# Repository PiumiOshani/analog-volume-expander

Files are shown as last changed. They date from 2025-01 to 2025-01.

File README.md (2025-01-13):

# Analog Volume Expander

**Real-time audio volume expander to enhance the dynamic range of audio signals.**

## 📖 Project Overview
This project involves the design and implementation of an **Analog Volume Expander**, which enhances the dynamic range of audio signals by applying upward expansion. It is tailored for applications like recording, broadcasting, and live sound systems.

### Key Features
- Real-time signal processing with minimal latency.
- User-configurable threshold and expansion ratio.
- Efficient **Control Voltage Processor** and **Voltage-Controlled Amplifier (VCA)**.
- Integrated notch filter to eliminate power line interference.
- Dual-layer PCB design and custom 3D-printed enclosure.

---

## 🛠 System Design
### Functional Block Diagram

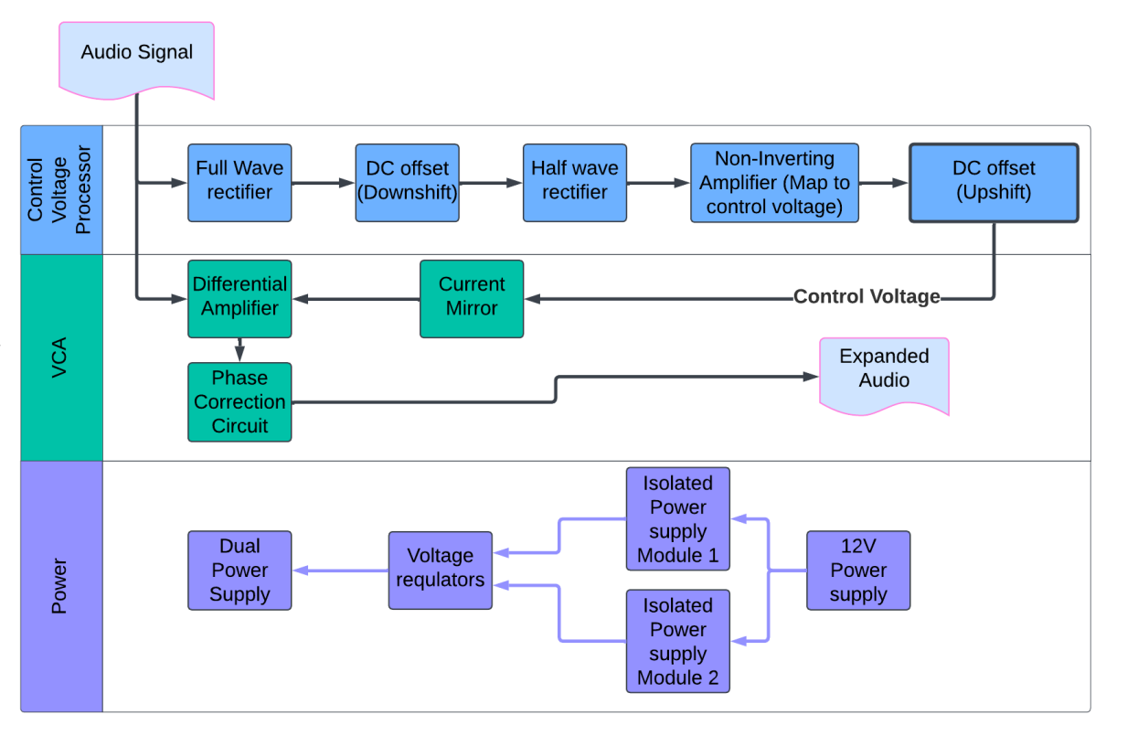
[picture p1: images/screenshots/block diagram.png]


### Core Components
- **Control Voltage Processor**: Processes the input signal to generate control voltages.
- **Voltage-Controlled Amplifier (VCA)**: Adjusts the gain dynamically.
- **Notch Filter**: Removes power line noise (50Hz).
- **Power Supply**: Provides stable and isolated power to the system.

---

## 📸 Project Highlights
### PCB Design
- **2-layer PCB Design**: Designed using Altium Designer, manufactured via JLCPCB.
- **Key Features**:
  - Efficient layout with minimal wiring.
  - Proper power-signal separation for reliability.

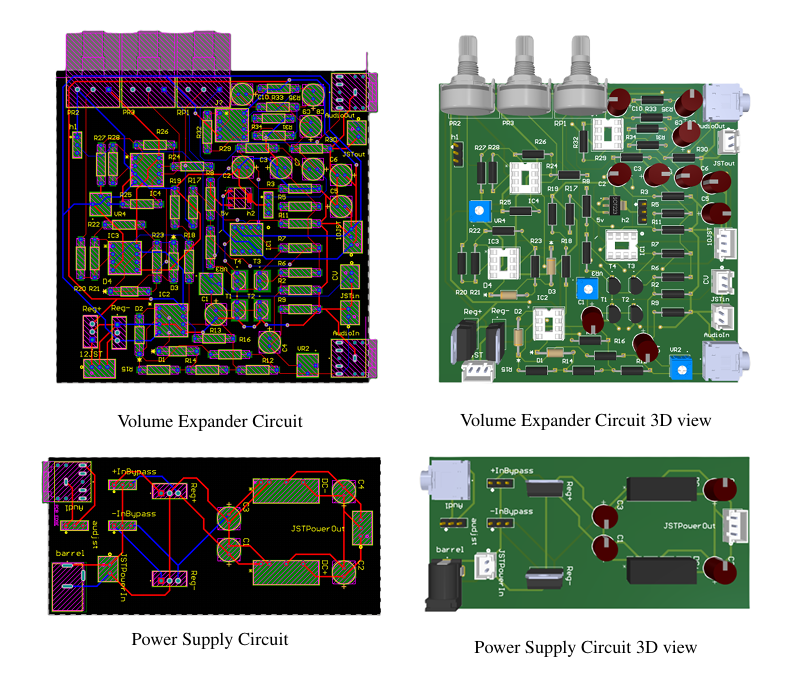
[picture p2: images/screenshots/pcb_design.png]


### Enclosure Design
- **3D-printed enclosure**:
  - Designed in SolidWorks.
  - Printed using durable PLA+ material.
- **Dimensions**: 154 mm × 116 mm × 70 mm.

<div style="display: flex; justify-content: space-between;">
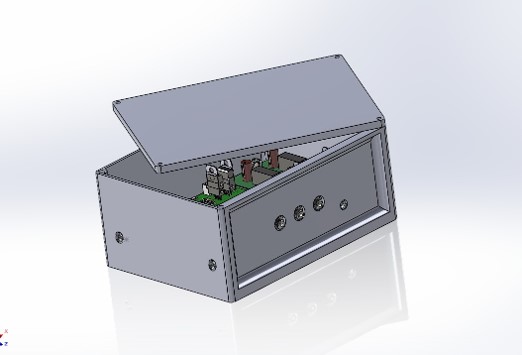
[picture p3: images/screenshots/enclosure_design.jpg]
    
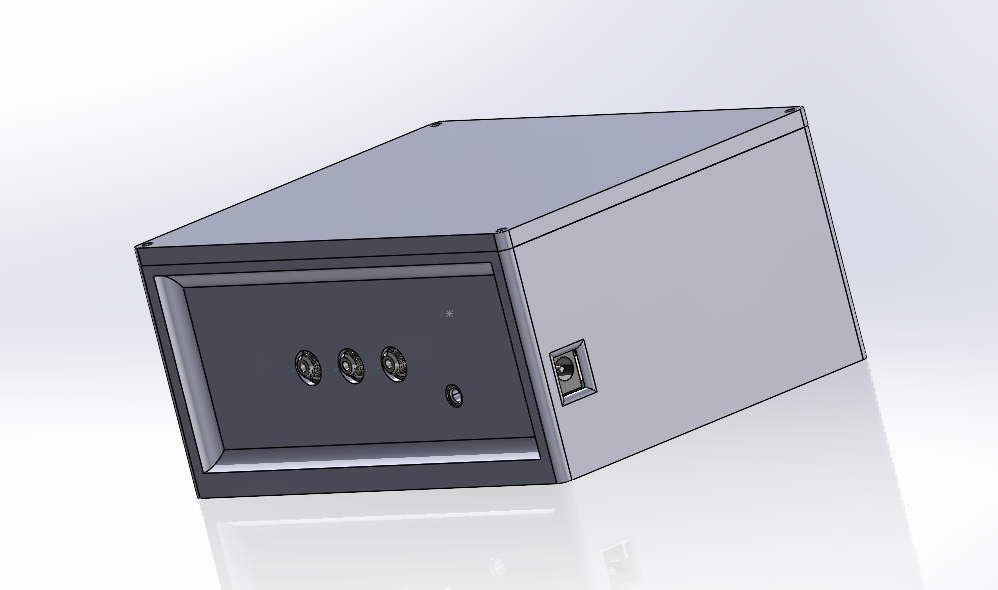
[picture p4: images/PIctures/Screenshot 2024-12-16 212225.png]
    
</div>

### Final Product

<div style="display: flex; justify-content: space-between;">
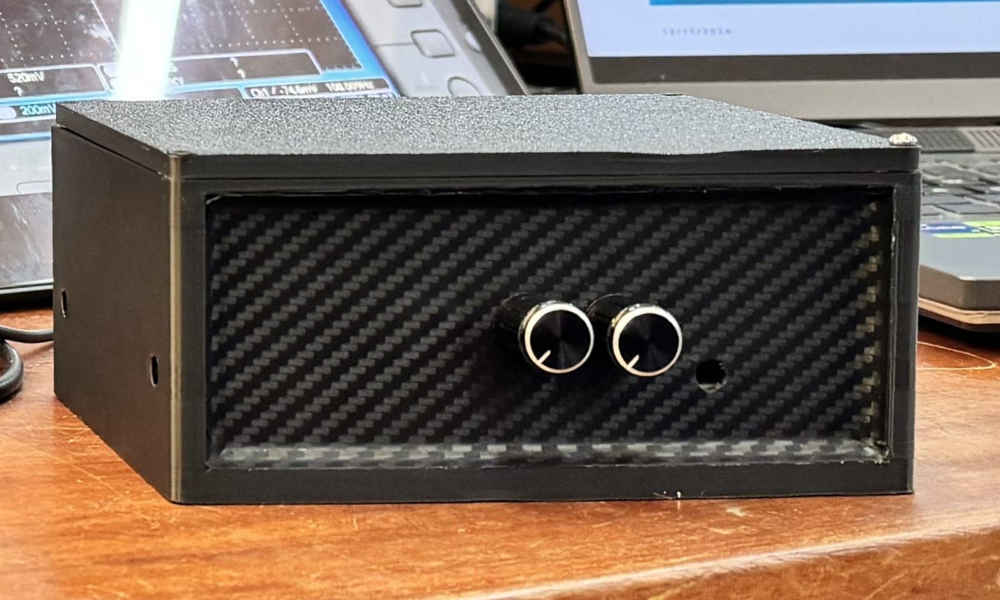
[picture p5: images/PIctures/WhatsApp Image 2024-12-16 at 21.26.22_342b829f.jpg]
    
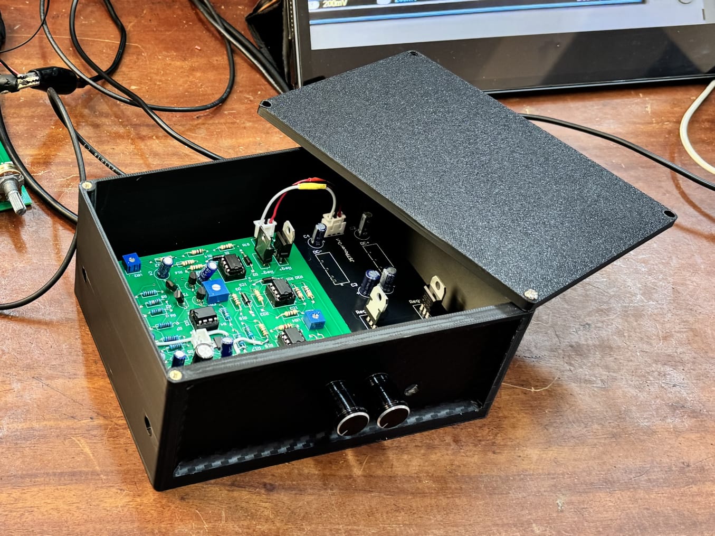
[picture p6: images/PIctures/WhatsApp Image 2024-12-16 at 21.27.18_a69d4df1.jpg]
    
</div>

 ## 👥 Group Members
 | Name | Index Number |Email|
|------|--------------|--------------|
 | Balasooriya B A P I | 220054N | balasooriyabapi.22@uom.lk
 | Dewasumithra M P O | 220112R |piumioshani@gmail.com|
 | Dineshara M C | 220128V |chandupadineshara@gmail.com|
 | Diunugala C H | 220143L |chamathdiunugala@gmail.com|

---




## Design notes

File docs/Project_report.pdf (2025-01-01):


Department of Electronic & Telecommunication Engineering, University of Moratuwa, Sri Lanka.

## Volume Expander

Group Members:

220054N | Balasooriya B.A.P.I.
220112R | Dewasumithra M.P.O.
220128V | Dineshara M.C.
220143L | Diunugala C.H.

Submitted in partial fulfillment of the requirements for the module EN 2091 Laboratory Practice and Projects

18/12/2024

Volume Expander | Group No : 5

Abstract
This report provides an overview of the design and implementation of a real-time audio volume expander to enhance dynamic range of audio signals. The system employs a control voltage processor and voltage-controlled amplifier (VCA) architecture to perform upward expansion of signals exceeding a user-defined threshold. Key components of the system includes a custom signal processor, a customized VCA circuit achieving 3-4 dB gain, and a notch filter to eliminate power line interference. The implementation features a dual-layer PCB design, custom 3D-printed enclosure, and isolated power supply for powering ciruits. Hardware testing and LTspice simulations validated the system’s functionality, demonstrating successful dynamic range enhancement for audio applications in Audio systems.

i

### Contents

1 Introduction and Functionality | 1
2 System Architecture | 1
3 Component Selection | 4
4 PCB Design | 5
5 Enclosure Design | 6
6 Final Product | 6
7 Software Simulation and Hardware Testing | 7
8 Conclusion & Future Works | 9
9 Contribution of Group Members | 9

ii

### 1 Introduction and Functionality

Dynamic range is a fundamental characteristic of an audio signals, it is the ratio between the loudest and quietest possible sounds in the audio signal. Maintaining a proper dynamic range of an audio signal is essential to achieve clarity, naturalness, and overall quality in audio reproduction. Due to recording limitations, signal processing, and noise, interference audio signals suffer from dynamic range compression leading to a loss of audio detail and reduced audio fidelity. [1]
A volume expander (commonly known as Audio dynamic range expander) is used to increase the dynamic range of an audio signal, by improving the difference between the quietest and loudest parts of the audio waveform. [2] This process restores the natural dynamics of an audio signal, reducing unwanted background noise and enhancing audio clarity. This report details the design and implementation of a custom audio dynamic range expander capable of real-time signal processing for applications in recording, broadcasting, and live sound systems. [3]

Volume Expander Functions by analyzing the In-

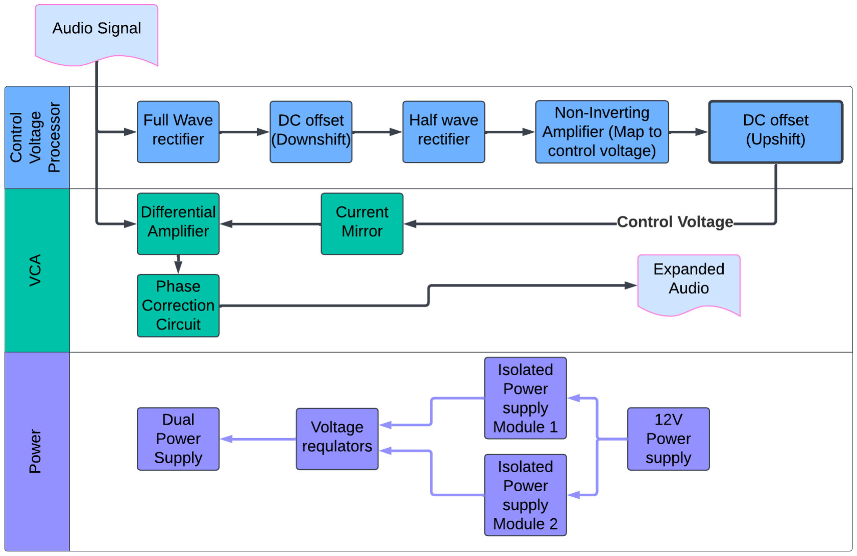
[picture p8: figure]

put audio signal and applying gain adjustments based on its amplitudes relative to a given threshold. Our implementation supports upward expansion of the audio signals which amplifies the levels of signals that exceeds the given threshold. The core functionality of the system is implemented through a control voltage processor which outputs a control voltage to a Voltage controlled amplifier (VCA), where gain applied to the audio signal is determined dynamically based on the amplitude of input signal. The user can configure the threshold and expansion ratio to customize the expander’s behavior. The system is designed to operate in real-time, ensuring minimal latency and seamless audio processing. It provides improved clarity and dynamic contrast, making it suitable for various audio applications, including music production, speech enhancement, and noise reduction.
Expander Parameters
- Threshold
The input level at which the expander activates. It triggers upward expansion for signals crossing above the threshold.
- Gain
The degree of amplification applied.

### 2 System Architecture

### 2.1 Functional Block Diagram

Figure 1: Functional Block Diagram

### 2.2 Control Voltage Processor

The Control Voltage Signal Processor is responsible for generating a control signal to dynamically adjust the gain of the audio signal using VCA. This processor includes several subsystems.

### 2.2.1 Full Wave Precision Rectifier

Converts the input audio signal to its absolute value, ensuring accurate amplitude detection. This component uses precision diodes and operational amplifiers to rectify both the positive and negative portions of the input signal without distortion.

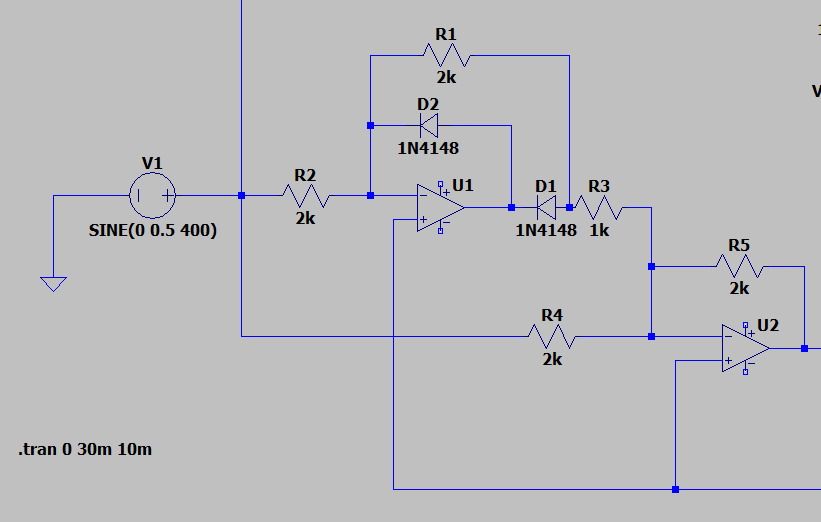
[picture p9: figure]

Figure 2: Full Wave Precision Rectifier Circuit

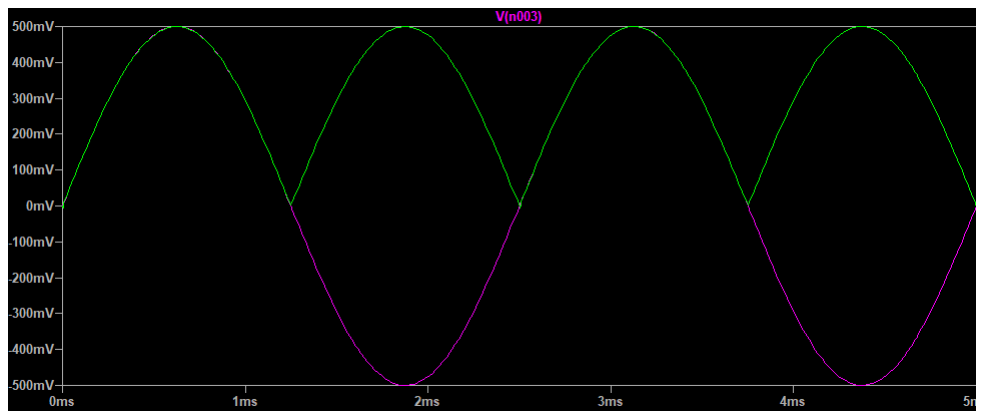
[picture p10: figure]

Figure 3: Full Wave Precision Rectifier Output

- Why Precision Rectifier? Standard diode rectifiers are unsuitable for low-amplitude signals due to forward voltage drops. Precision rectifiers eliminate this limitation, allowing accurate rectification of even millivolt-level signals.

### 2.2.2 DC offset(Downshift)

Adds a negative DC bias to the rectified signal to ensure that it operates within the appropriate voltage range for subsequent stages. Ideally adjusted to the unity gain voltage of the voltage controlled amplifier. This reference voltage depends on the threshold value that the user can control.

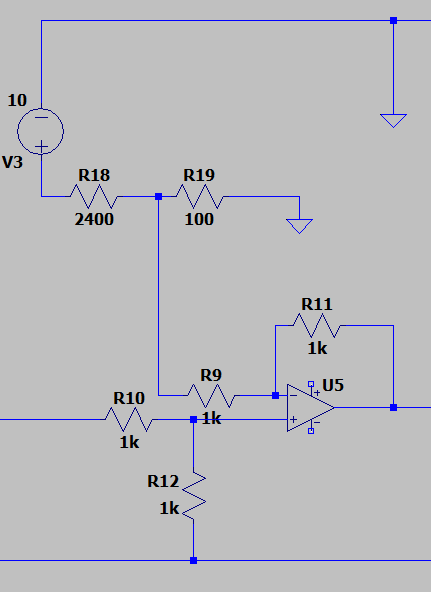
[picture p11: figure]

Figure 4: DC Downshift Circuit

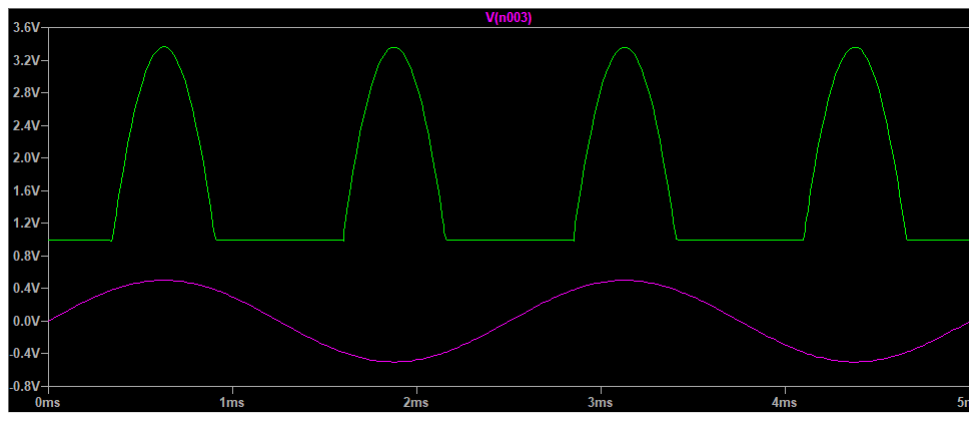
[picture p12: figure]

Figure 5: DC Downshift Output

### 2.2.3 Half Wave Precision Rectifier

Cutoff the signal that lies below the threshold level and extract accurate envelope of the audio signal. The resulting waveform represents the instantaneous amplitude of the signal above the threshold. A half wave precision rectifier is used to rectify signals with amplitudes as low as a few millivolts.

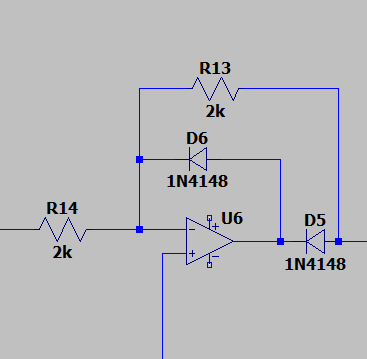
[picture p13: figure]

Figure 6: Half Wave Precision Rectifier Circuit

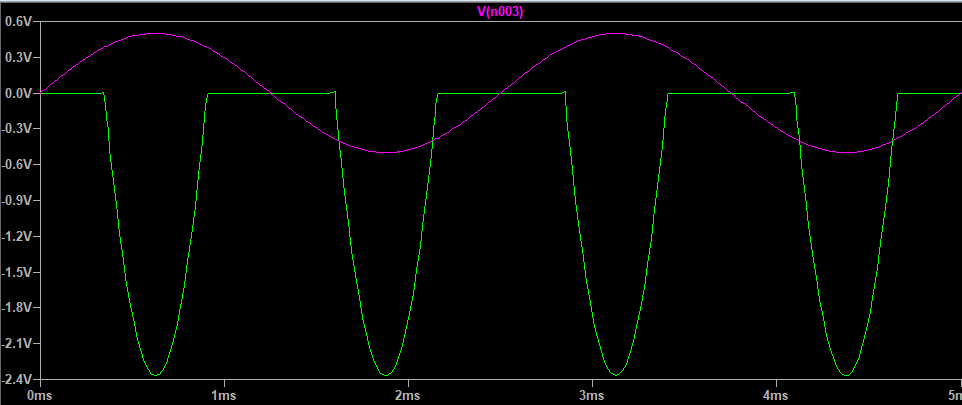
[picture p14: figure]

Figure 7: Half Wave Precision Rectifier Output

### 2.2.4 Non Inverting Amplifier

Amplifies the processed signal without inverting its phase. The gain of this amplifier is adjustable to scale the control voltage for effective operation of the Voltage Controlled Amplifier (VCA). A potentiometer in the feedback loop allows user-configurable gain.

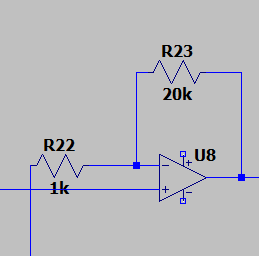
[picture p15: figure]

Figure 8: Non Inverting Amplifier Circuit

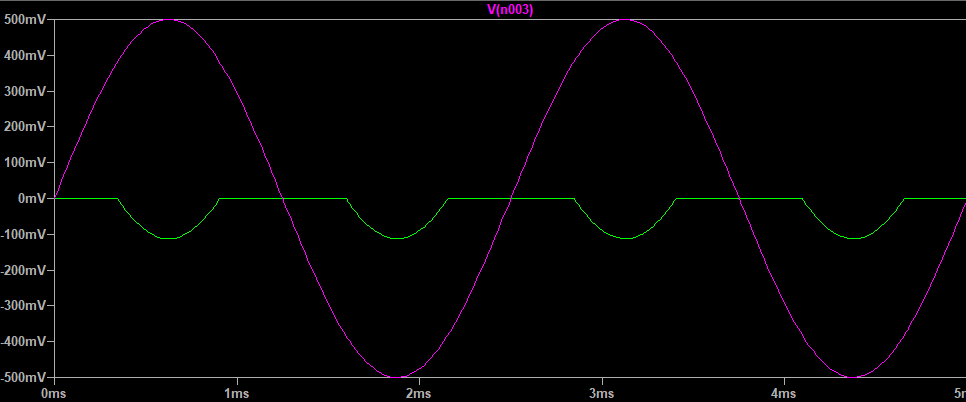
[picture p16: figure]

Figure 9: Non Inverting Amplifier Output

### 2.2.5 DC offset(Up-shift)

Reintroduces a positive DC bias to the signal after processing, ensuring DC offset aligns with the unity gain voltage of the voltage controlled amplifire. The unity gain control voltage of the VCA is 1 V. This output is used as control voltage of the voltage controlled amplifier.

### 2.3 Voltage Controlled Amplifier

The Voltage Controlled Amplifier (VCA) dynamically adjusts the gain of the input audio signal based on the control voltage generated by the processor. It operates at the center of the expander, providing real-time modulation of the signal’s amplitude.

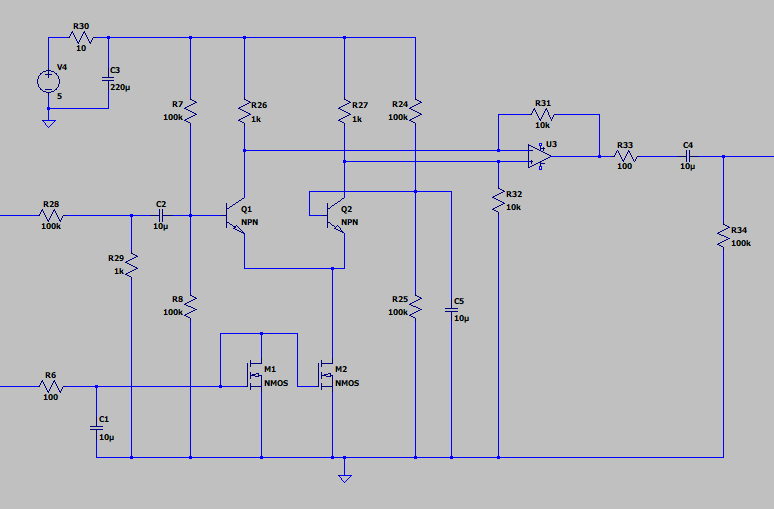
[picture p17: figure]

Figure 10: Voltage Controlled Amplifier (VCA)

The gain of the VCA is proportional to the emitter current of the differential amplifier,

G =

Ie × Rload
VT

Emitter current Ie is generated by the control voltage (VCV ) through resistor RCV :

IE =

VCV − VBE

RCV
Thus, the gain G can be expressed as:

G =

(VCV − VBE) × Rload

RCV × VT
Simplifying further:

G =

(VCV − 0.7) × 1 × 10³
10 × 10³ × 25 × 10⁻³

G = (VCV − 0.7) × 4

- Maximum gain possible: 9 to 10 dB
- Required gain according to criterion: 3 to 4 dB

### 2.4 Notch Filter

The notch filter is designed to eliminate power line interference, which typically occurs at 50 Hz. A Twin-T Notch Filter with feedback is implemented, with a calculated notch frequency of 50 Hz,

fn =

1
2πRC =

10³
2π × 6.8 × 0.47

= 50Hz (1)

### 2.5 Power Supply

Dual power supply using isolated power modules. This provides stable power to operational amplifiers and the VCA, ensuring reliable performance. Module: B1212S-2W

- Maximum Power: 2W
- Maximum Current: 244 mA
- Required Current: 130 mA – 150 mA

### 3 Component Selection

### 3.1 TL072CP opamp

We selected the TL072CP
as our operational amplifier due to several key advantages. It offers a high slew rate of 13 V/µs, which helps prevent signal distortion, with a low power consumption of 1.4 mA, making it energy efficient. In addition, it provides high input impedance and low output impedance, ensuring effective signal amplification, and its low noise characteristics make it suitable for sensitive applications. As alternatives, the OPA2134 can be used due to its ultra-low noise performance, and NE5532 can be used due to its low noise and higher drive capability. But they come at a higher cost.

### 3.2 UF4007 diode

We used the UF4007 diode
due to several reasons. It has a consistent forward
voltage drop of approximately 0.7V over a range
of currents and an ultra-fast reverse recovery time of around 75ns, making it highly suitable for audio frequency signals. As alternatives, Schottky diodes can be considered because they have an ultra-low forward voltage drop of around 0.2V, which reduces power losses. Another option is the 1N4148 diode, which is a low-cost solution suitable for low-current circuits, though it is less robust compared to the UF4007.

### 3.3 BC547 transistor

We used the BC547 transistor for the differential amplifier and current mirror in the voltage-controlled amplifier. The BC547 was
chosen due to its low noise characteristics and good low-frequency response. Also it is a very cheap and widely available option, making it ideal for cost-effective designs.

### 3.4 Hilink B1212S 2WR3 isolated power

supply module

We used the B1212S-2WR3
module to get +12V and -
12V isolated outputs for our power supply circuit. This module is small, efficient (up to 90%), and has low
power consumption. It also provides short circuit protection and works well in a wide temperature range (-40°C to +85°C). It is ideal for stable and isolated power needs.

### 4 PCB Design

We have designed two PCBs for volume expander part and power supply using Altium Designer software and printed them via JLCPCB. The design followed the manufacturing constraints for manufacturing by JLCPCB. [4]

PCB Details

- Volume Expander PCB:
Dimensions are 10 cm × 10 cm.
- Power Supply PCB:
Dimensions are 10 cm × 4.75 cm.

Design Specifications

- Layer Count:
Both PCBs are two-layered.
- Via Sizes: 1.27 mm.
- Trace Sizes:

– Power Lines: 0.635 mm.

– Other Traces: 0.381 mm.

Design Considerations

- The PCBs are designed to minimize the use of wires, ensuring an efficient layout.
- Proper separation between power and signal traces is maintained to reduce interference and improve reliability.
- The use of two-layers balances out costeffectiveness with design complexity

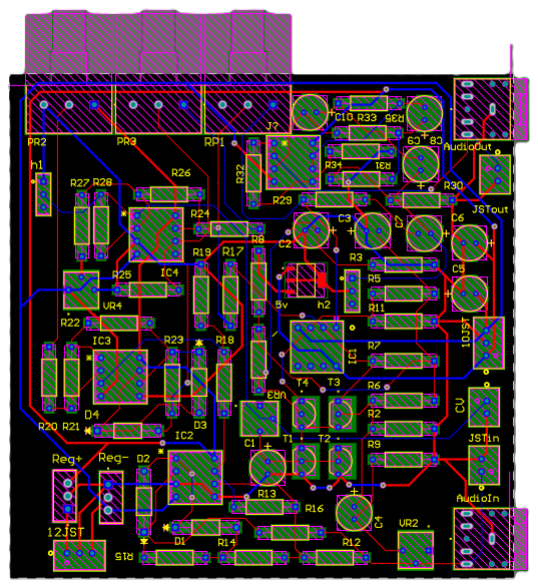
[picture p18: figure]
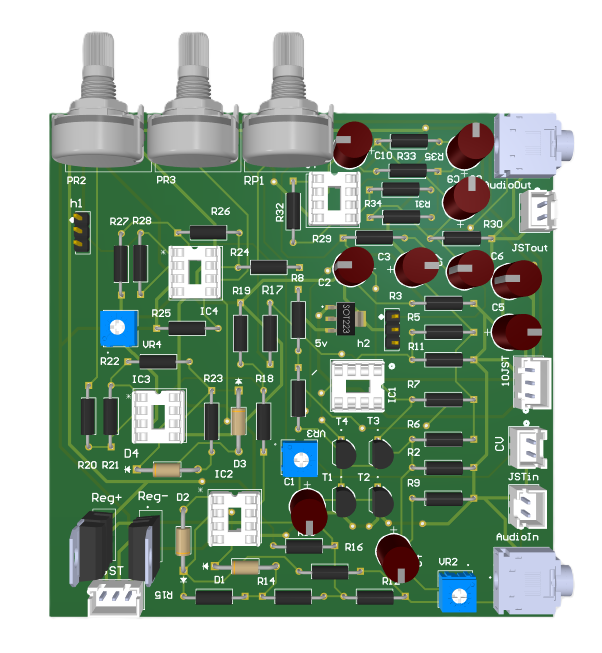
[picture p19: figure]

Volume Expander Circuit | Volume Expander Circuit 3D view

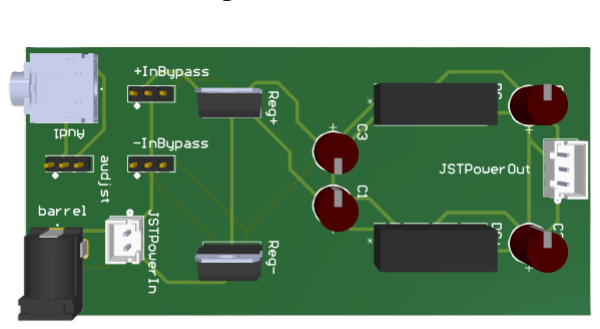
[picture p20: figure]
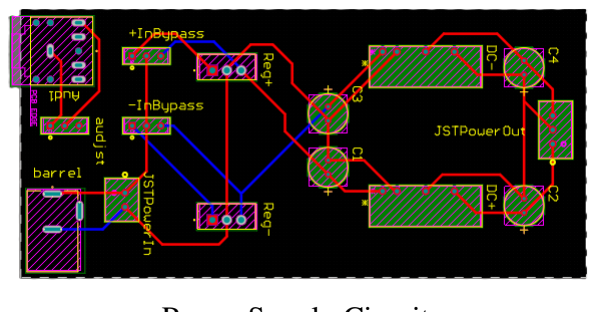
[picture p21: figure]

Power Supply Circuit | Power Supply Circuit 3D view

### 5 Enclosure Design

- Structure:
The enclosure features a simple design consisting of a box and a detachable lid for easy access to internal components.
- Software:
The design was created using SolidWorks.
- Material:
3D printed using PLA+, a durable and slightly flexible material, ideal for creating robust and lightweight enclosures.
- Dimensions:
154 mm × 116 mm × 70 mm

### 6 Final Product


Figure 11: Volume Expander

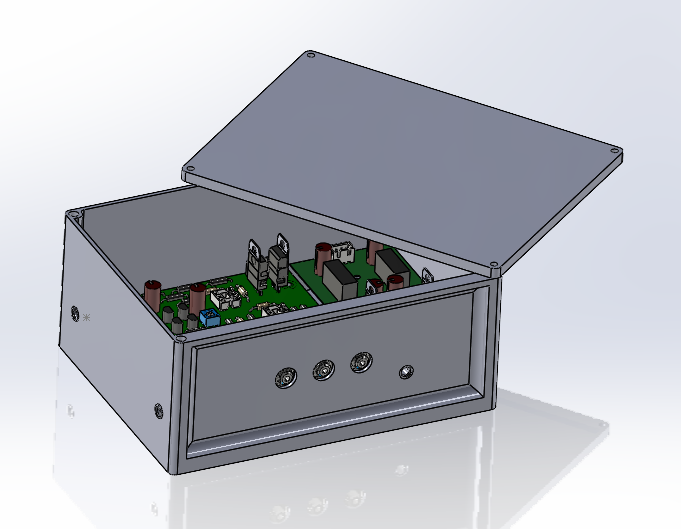
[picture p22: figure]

Figure 12: Volume Expander internal view

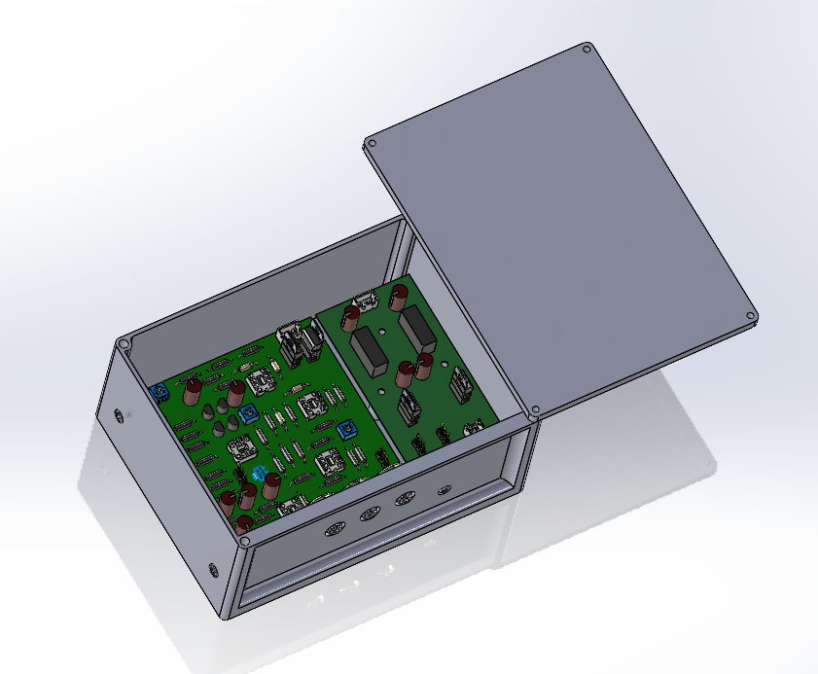
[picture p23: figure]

### 7 Software Simulation and Hardware Testing

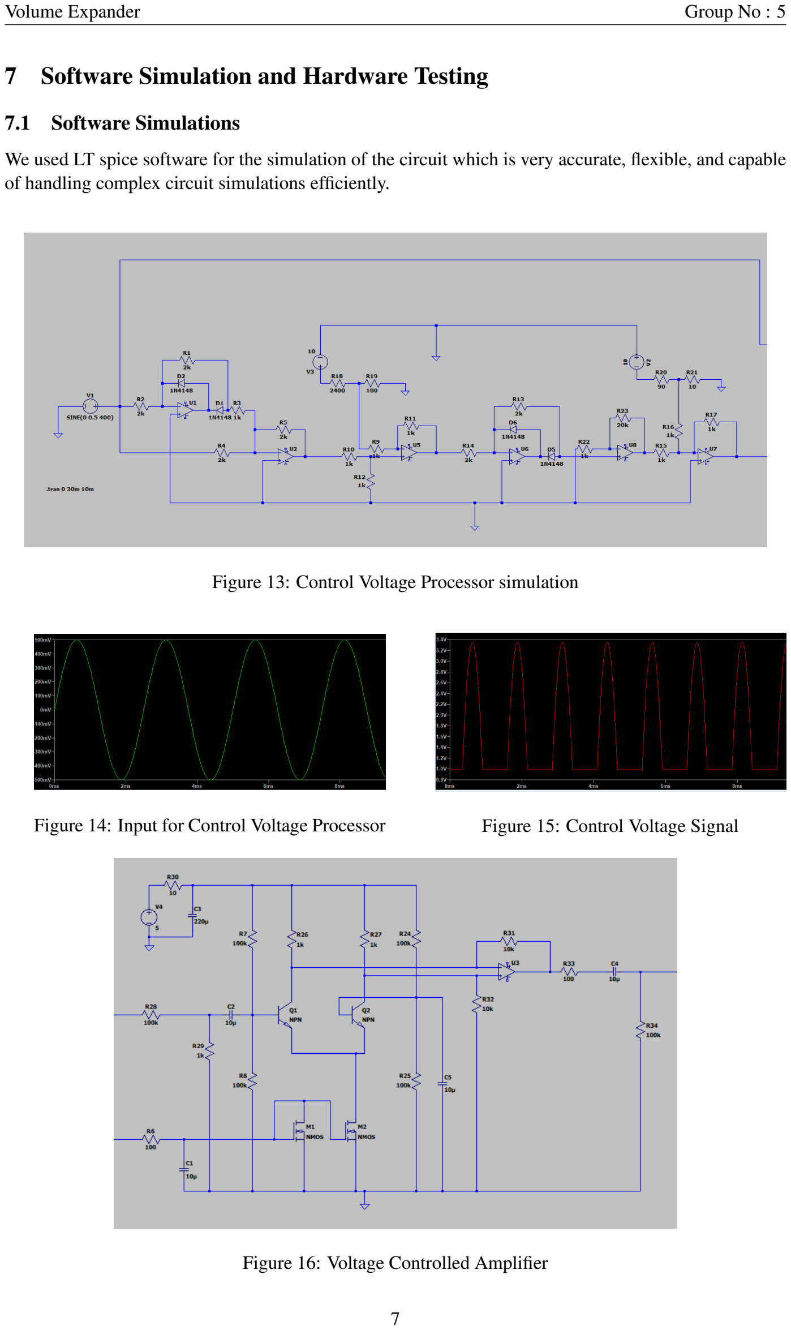
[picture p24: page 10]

### 7.1 Software Simulations

We used LT spice software for the simulation of the circuit which is very accurate, flexible, and capable of handling complex circuit simulations efficiently.

Figure 13: Control Voltage Processor simulation

Figure 14: Input for Control Voltage Processor | Figure 15: Control Voltage Signal

Figure 16: Voltage Controlled Amplifier

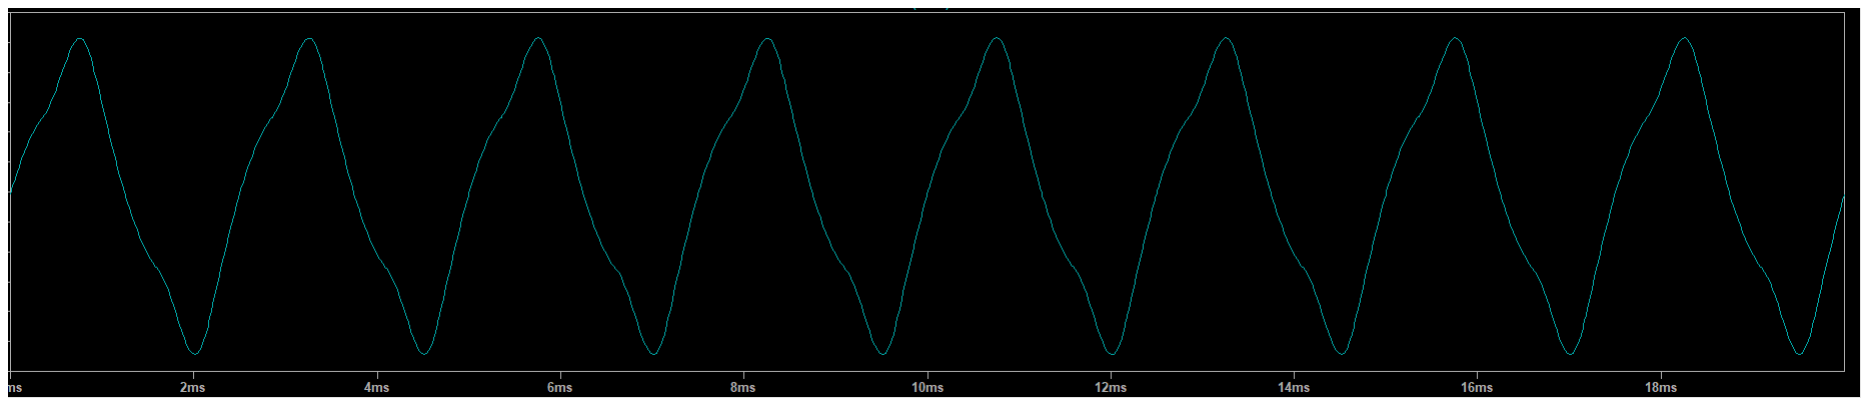
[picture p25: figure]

Figure 17: Voltage Controlled Amplifier Output

### 7.2 Hardware Testing

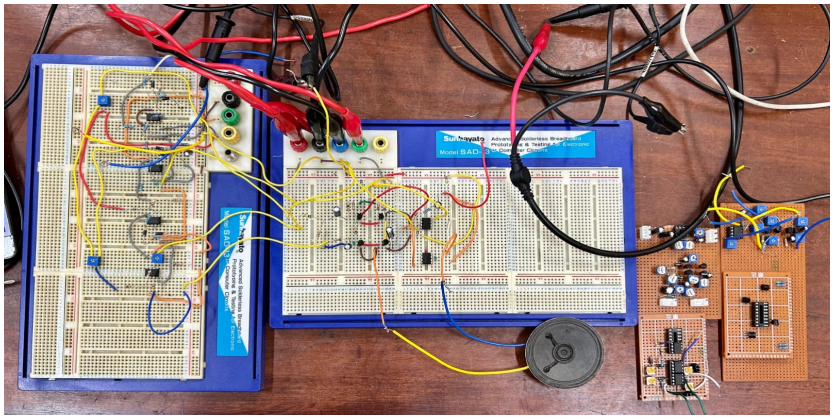
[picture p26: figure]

Figure 18: Breadboard Implementation

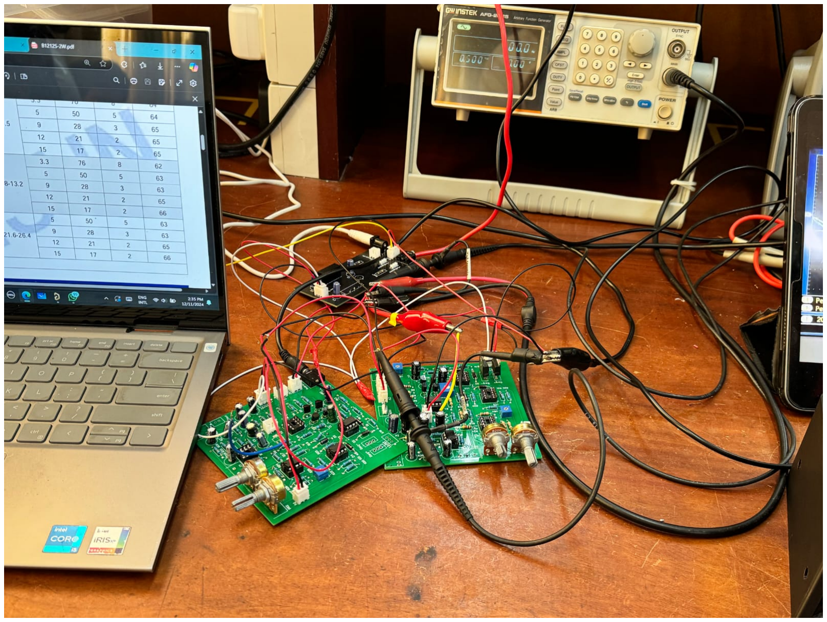
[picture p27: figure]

Figure 19: PCB testing

### 8 Conclusion & Future Works

In this project, we successfully designed and implemented an upward volume expander. The upward expander amplifies signals above a set threshold, enhancing the clarity and depth of audio signals. Despite the challenges, our team was able to build this system from scratch, which significantly broadened our understanding of analog electronics. One of the primary challenges was the limited availability of resources, both online and from other sources, on the design and implementation of such systems. As a result, we relied heavily on theoretical concepts and iterative experimentation to develop functional circuit components. This process deepened our practical knowledge of operational amplifiers, rectifiers, voltage-controlled amplifiers, and filters, while strengthening our problem solving skills.
For future work, we aim to extend this project by incorporating a downward expander. The downward expander will attenuate signals below a set threshold, further improving the dynamic range control of the system. This addition will make the system more versatile and applicable for a wider range of audio processing needs.
This project provided invaluable hands-on experience and enhanced our understanding of dynamic range processing in audio systems. We are confident that the skills and knowledge gained will serve as a strong foundation for future endeavors in analog and digital electronics.

### Acknowledgments

We extend our heartfelt gratitude to everyone who contributed to the successful completion of our volume expander project. First and foremost, we express our sincere appreciation to our project supervisor, Mr. S. Rukshanth, Mr.Thilanka Udana, Ms.Dinithi Fernando, Mr.Sandun Ranasinghe for their invaluable guidance, insights, and unwavering support throughout the development process. We also acknowledge the dedication, hard work, and collaborative efforts of every team member, which were instrumental in achieving the project objectives. Our special thanks go to Dr. Sampath Perera, Dr. Jayathu Samarawickrama, Dr. Chamira Edirisooriya, and Dr. Wageesha Manamperi for their constructive feedback during project reviews, which greatly contributed to refining and enhanc-

ing our design.
Additionally, we are grateful for the encouragement and assistance provided by our peers and colleagues, whose support further motivated us during this journey. This project has been a collective effort, and the collaborative environment enabled us to explore, innovate, and overcome challenges effectively.
The invaluable experience gained from this project will undoubtedly serve as a foundation for our future endeavors.

### 9 Contribution of Group Members

Index Number | Tasks
220054N | Circuit design ,PCB de-sign, Documentation
220112R | Circuit design, Enclosure design, PCB testing
220128V | Circuit design, Enclosure design, Documentation
220143L | Circuit design, PCB de-sign, PCB testing

### References

[1] R. HD-Audio. Audio dynamics processing: Compression, expansion, limiting, and gating. [Online]. Available: https://www.realhdaudio.com/?p=3318
[2] iZotope. | Audio | dynamics | 101:
Compressors, | limiters, | expanders,
and | gates. | [Online]. | Available:
https://www.izotope.com/en/learn/audiodynamics-101-compressorslimiters-expanders-andgates.html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
[3] MathWorks. | Expander | sys-
tem | object. | [Online]. | Available:
https://www.mathworks.com/help/audio/ref/expandersystem-object.html
[4] Pcb capabilities and limitations. Available: https://jlcpcb.com. JLCPCB. Accessed: Dec.
23, 2024.

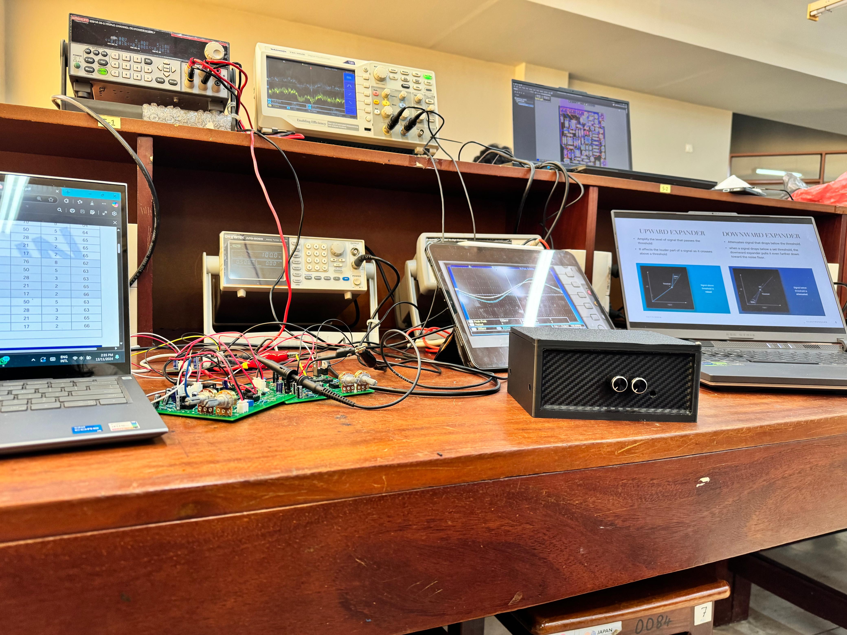
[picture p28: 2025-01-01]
images/hardware/final_presentation.jpg

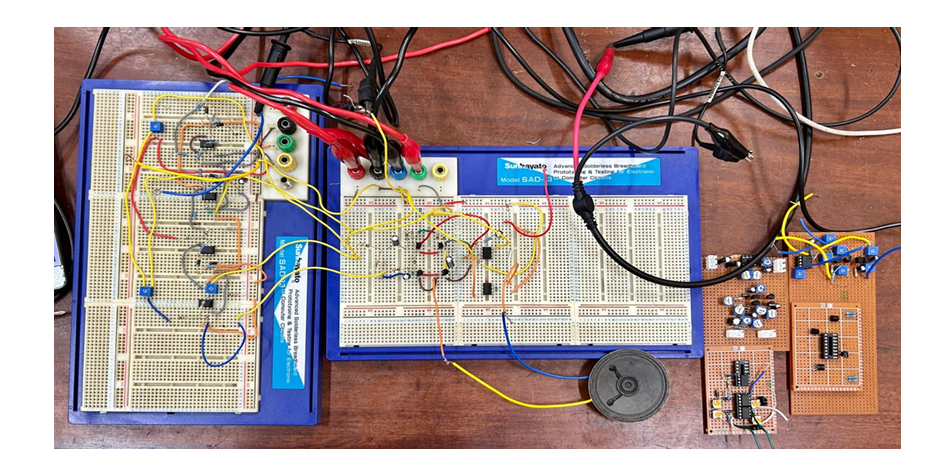
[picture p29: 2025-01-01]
images/hardware/Breadboard Implementation.png

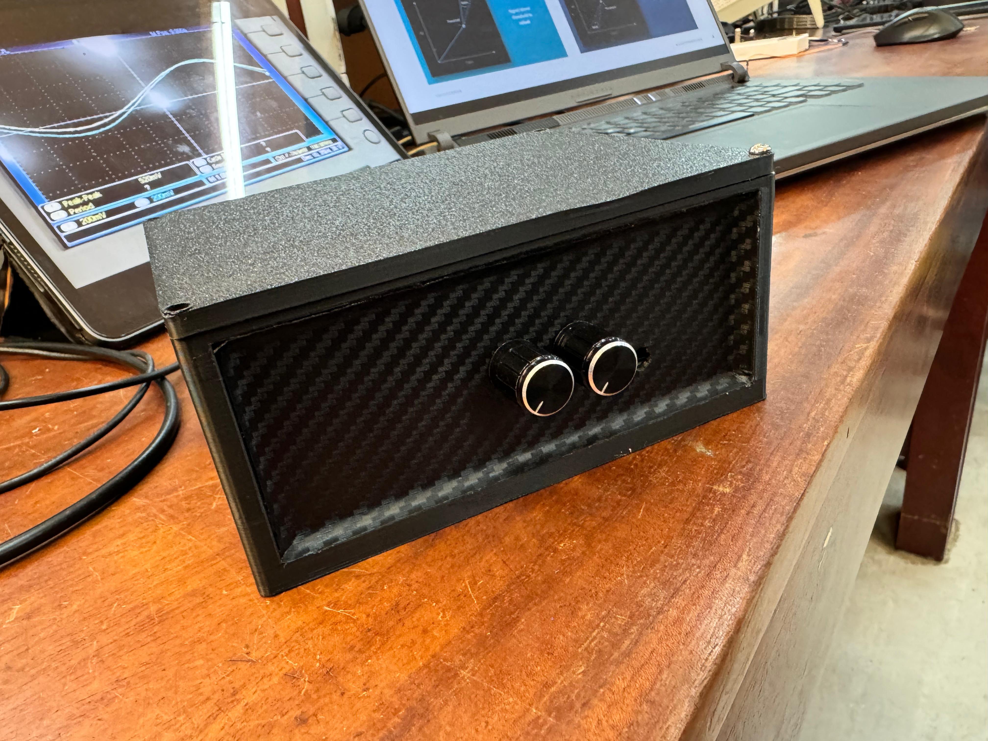
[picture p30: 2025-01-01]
images/hardware/final_product.jpg

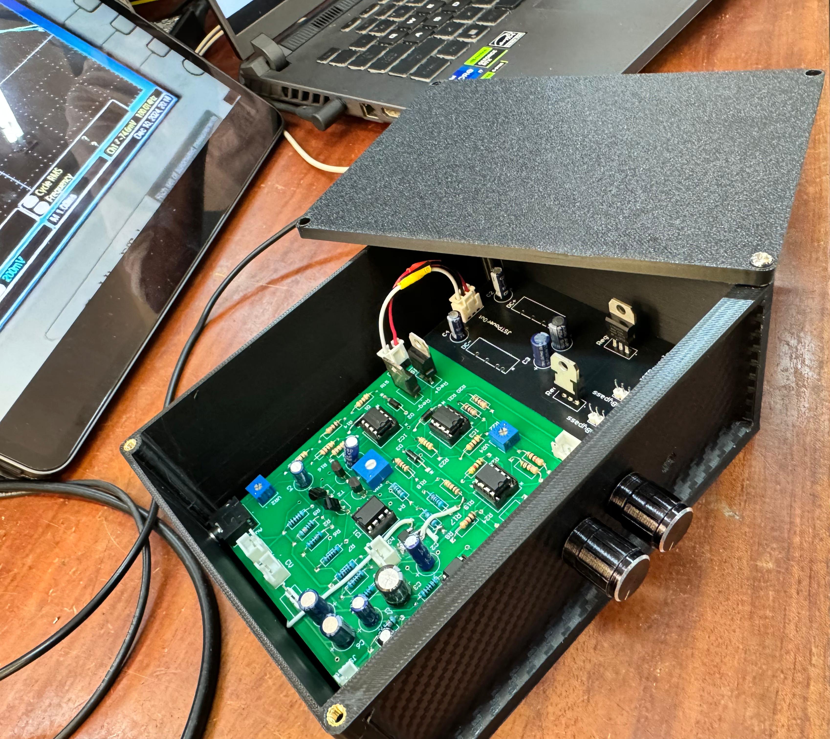
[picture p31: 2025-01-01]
images/hardware/final_product_insideview.jpg

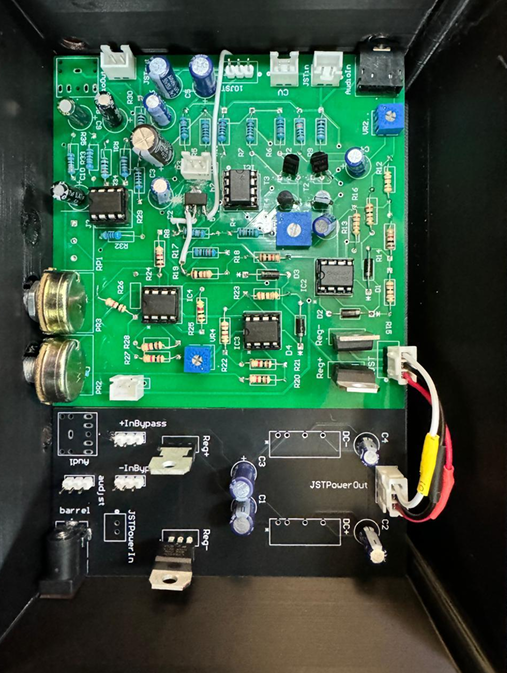
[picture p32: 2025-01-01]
images/hardware/pcb design.png

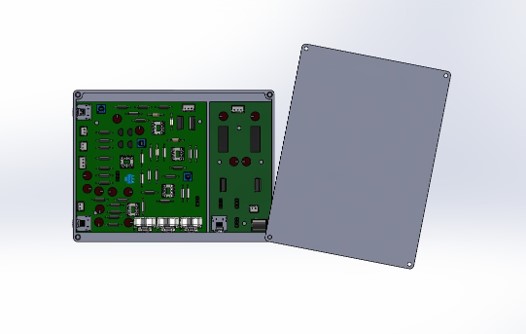
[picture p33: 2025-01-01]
images/screenshots/enclosure design inside.jpg

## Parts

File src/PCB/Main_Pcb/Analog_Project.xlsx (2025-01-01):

Line # | Name | Description | Designator | Quantity | Manufacturer 1 | Manufacturer Part Number 1 | Manufacturer Lifecycle 1 | Supplier 1 | Supplier Part Number 1 | Supplier Unit Price 1 | Supplier Subtotal 1
 | 4_PinSocket | No Description Available | 4_PinSocket | 1
 | 3pinJST | No Description Available | 10JST, 12JST | 2
 | Audioport | 3.5 mm, Stereo, Right Angle, Through Hole, 3 Conductors, 2 Internal Switches, Audio Jack Connector | AudioIn, AudioOut | 2
 | capacitor | 10u | C1, C2, C4, C7 | 4
 | capacitor | 220u | C3 | 1
 | capacitor | 33u | C5, C6 | 2
 | capacitor | No Description Available | C8, C9, C10 | 3
 | 2pinJST | No Description Available | CV, JSTin, JSTout | 3
 | UF4007 | No Description Available | D1, D2, D3, D4 | 4
 | 8pinBase | No Description Available | IC2, IC3, IC4, J? | 4
 | roraryPotentiometer | 10kohm | PR2 | 1
 | roraryPotentiometer | 20kohm | PR3 | 1
 | 1/4W_Resistor | 100kohm | R2, R3, R4, R6, R30 | 5
 | 1/4W_Resistor | 1kohm | R5, R7, R9, R14, R17, R18, R19, R20, R21, R24, R25, R26, R27, R28 | 14
 | 1/4W_Resistor | 10ohm | R8 | 1
 | 1/4W_Resistor | 10kohm | R11 | 1
 | 1/4W_Resistor | 2kohm | R12, R13, R15, R16, R22, R23 | 6
 | 1/4W_Resistor | 100ohm | R29 | 1
 | 1/4W_Resistor | No Description Available | R31, R32, R33, R34, R35 | 5
 | +10vregulator | Linear Voltage Regulator IC Positive Fixed 1 Output 1.5A TO-220AB | Reg-, Reg+ | 2
 | roraryPotentiometer | 20Kohm | RP1 | 1
 | BC550 | No Description Available | T1, T2, T3, T4 | 4
 | Trimmer | 10kohm | VR1, VR3 | 2
 | Trimmer | 100kohm | VR2 | 1
 | Trimmer | 1kohm | VR4 | 1
 | M3 headed inserts |  |  | 5
 | cap for variable resistors |  |  | 5
 | charging module

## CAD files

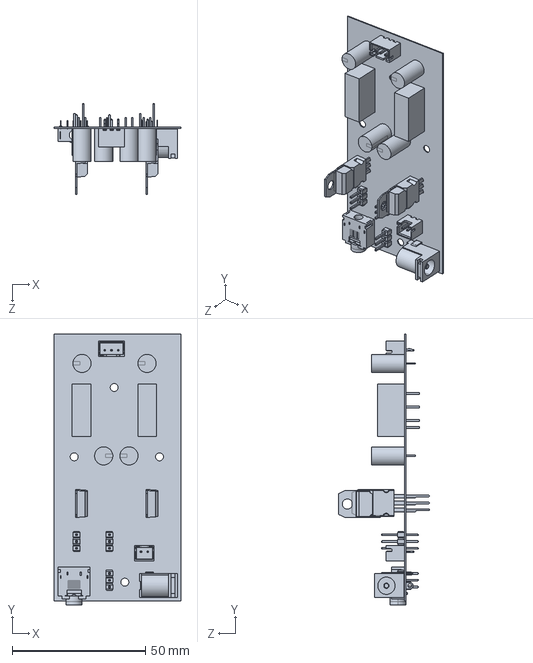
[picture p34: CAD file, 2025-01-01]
enclosure_design/Power_Pcb.step.SLDPRT
47.5 x 101.6 x 34.0 mm

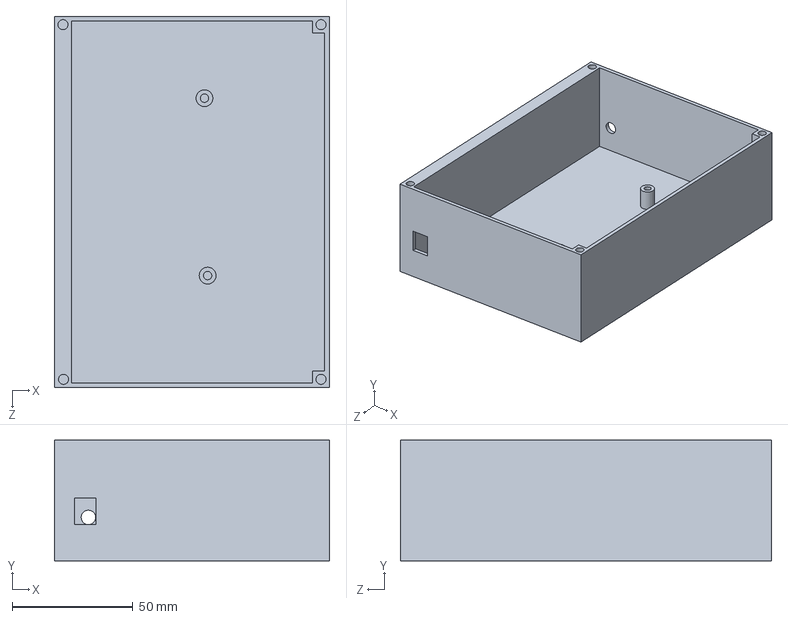
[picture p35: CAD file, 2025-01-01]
enclosure_design/Part4.SLDPRT
114.0 x 50.0 x 154.0 mm

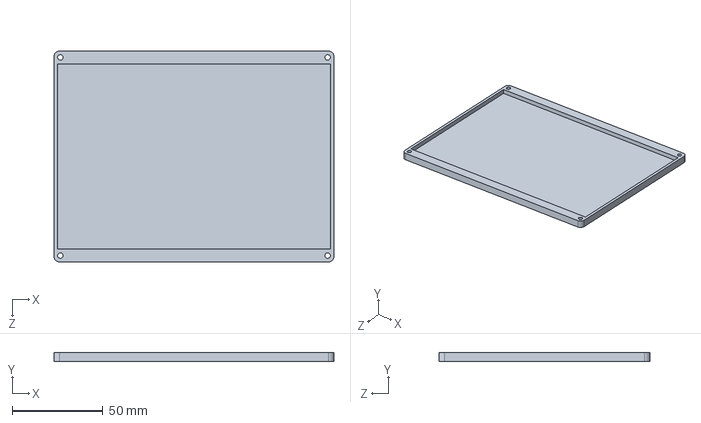
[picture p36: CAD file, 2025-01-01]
enclosure_design/volume expander top.SLDPRT
154.0 x 5.00 x 116.0 mm

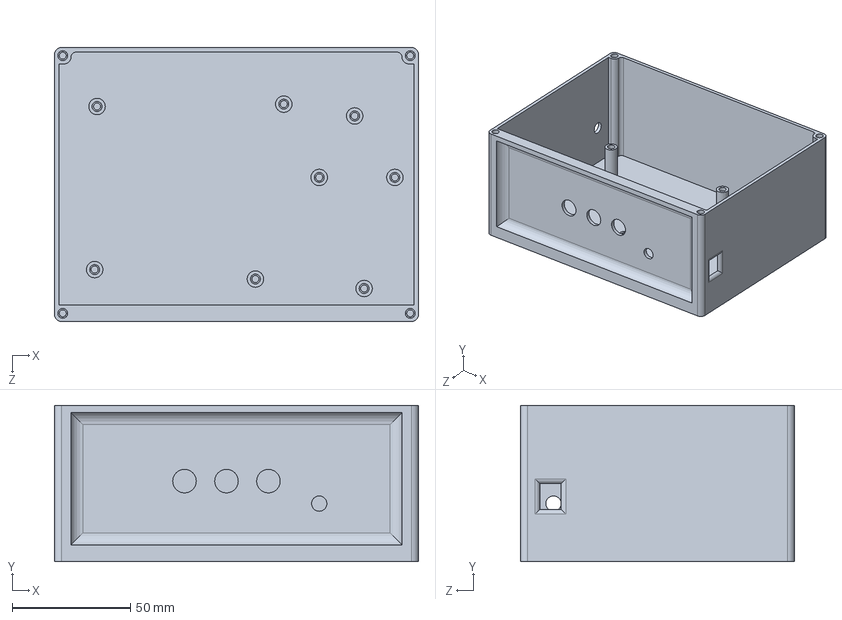
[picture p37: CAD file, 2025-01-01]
enclosure_design/volume expander.SLDPRT
154.0 x 66.0 x 116.0 mm

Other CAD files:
enclosure_design/Power_Pcb.step

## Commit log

2025-01-01 simulation files for control voltage circuit
2025-01-01 schematics and PCB design files
2025-01-01 3D enclosure design files
2025-01-01 add enclosure design
    [Part4.SLDPRT, Power_Pcb.step, Power_Pcb.step.SLDPRT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]
2025-01-01 Add schematics and PCB design files
    [Power_Pcb.PcbDoc, Power_Pcb.PrjPcb, Power_Pcb.SchDoc]
2025-01-01 add main pcb
    [Analog_Project.xlsx]
2025-01-01 Add main pcb files
    [AnalogProject.PcbDoc, AnalogProject.SchDoc, Analog_Project.PrjPcb]
